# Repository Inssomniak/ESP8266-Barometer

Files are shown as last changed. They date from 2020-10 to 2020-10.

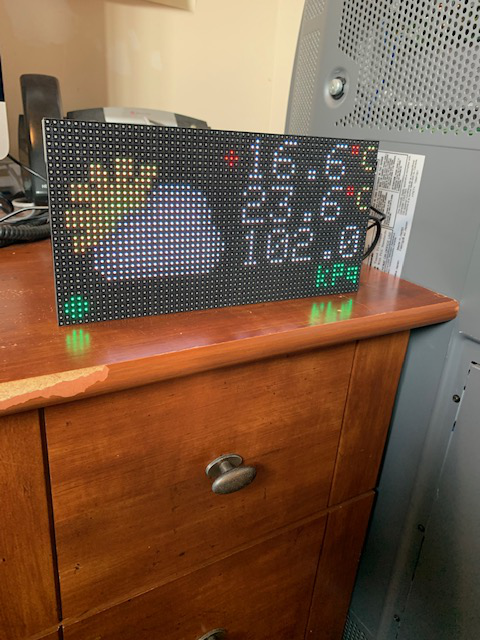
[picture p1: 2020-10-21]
images/image-4.jpg

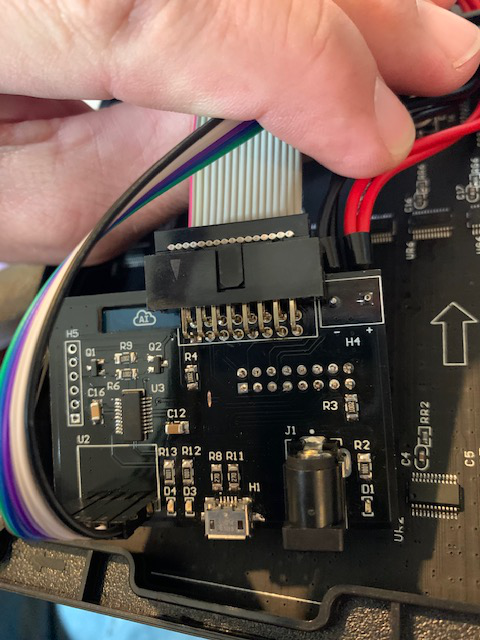
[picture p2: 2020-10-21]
images/IMG_0619.jpg

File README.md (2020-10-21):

# ESP8266-Barometer
ESP8266 Based Barometer on HUB75 LED Matrix with external sensor.  See https://github.com/2dom/PxMatrix for wiring, and information on the Library.
Arduino IDE

LED Matrix barometer on an AliExpress P5 Led Matrix 1/16 scan. Uses pxMatrix library.  BMP280 Pressure/temp sensor.
PCB Designed and made by me with onboard nodemcu style TTL serial converter, ESP-07 type module, 3v3 voltage, support for all scan types.
PCB Gerber is missing a pulldown resistor 10k on GPIO15, I soldered it across to ground right on the ESP-07 module
Depending on your LED Matrix, you have to cut a trace for E Scan line or remove the pins from the header before assembly so the flash GPIOs arent accidentally pulled LOW.

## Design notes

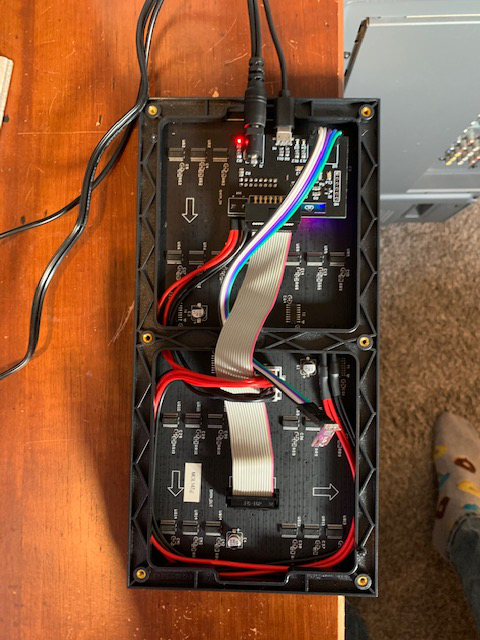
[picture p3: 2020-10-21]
images/image.jpg

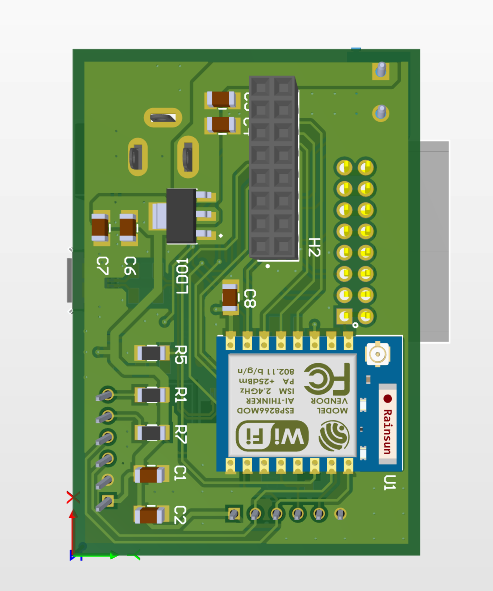
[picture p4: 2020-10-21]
Barometer Gerbers/3D/Screenshot_6.png

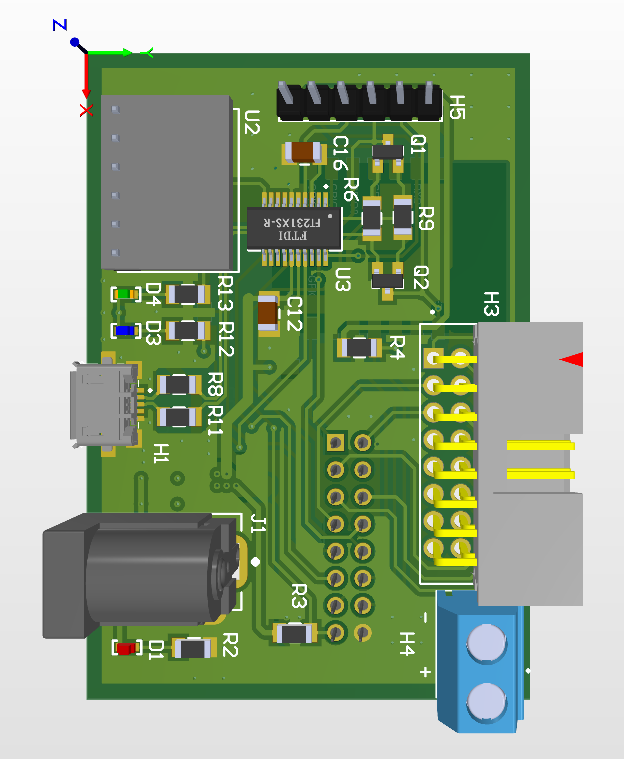
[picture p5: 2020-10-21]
Barometer Gerbers/3D/Screenshot_5.png

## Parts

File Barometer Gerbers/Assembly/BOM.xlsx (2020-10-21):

Designator | Comment | Description | Footprint | Manufacturer | Mfr.PN | Quantity
U3 | FT231XS-R | USB Bridge, USB to UART USB 2.0 UART Interface 20-SSOP | FT231XS-R | FTDI | FT231XS-R | 1
U2 | GY_BMP280_MODULE | environmental sensor with temperature, barometric pressure | BMP280_MODULE | KOOBOOK | KB039 | 1
U1 | ESP8266-07 | self-contained Wi-Fi network solution | ESP8266-07_MODULE | Reland Sung | 722704676397 | 1
R8, R11 | 27R | 27 ±5% 0.25W, 1/4W Chip Resistor 1206 (3216 Metric) Automotive AEC-Q200 Thick Film | R3216 | Stackpole Electronics Inc | RMCF1206JT27R0 | 2
R2, R12, R13 | 1K | 1 ±1% 0.25W, 1/4W Chip Resistor 1206 (3216 Metric) Automotive AEC-Q200 Thick Film | R3216 | Stackpole Electronics Inc | RMCF1206FT1K00 | 3
R1, R3, R4, R5, R6, R7, R9 | 10K | 10 ±1% 0.25W, 1/4W Chip Resistor 1206 (3216 Metric) Automotive AEC-Q200 Thick Film | R3216 | RMCF1206FT10K0 | Stackpole Electronics Inc | 7
Q1, Q2 | MMBT3904 | Bipolar _BJT_ Transistor NPN 40V 200mA 270MHz 350mW Surface Mount SOT-23-3 | MMBT3904 | STMicroelectronics | MMBT3904 | 2
LDO1 | TLV1117LV33DCYR | 1-A, low-dropout voltage regulator 4-SOT-223 -40 to 125 | TLV1117LV33DCYR | Texas Instruments | TLV1117LV33DCYR | 1
J1 | PJ-002A | 2,0 x 6,5 mm, 2,5 A, Yatay, AÃ§Ä±k Delik, Dc GÃ¼Ã§ JakÄ± KonnektÃ¶rÃ¼ | PJ-002A | CUI Devices | PJ-002A | 1
H5 | PH1-06-UA | Connector Header Through Hole 6 position 0.100" (2.54mm) | PH1-06-UA | Adam Tech | PH1-06-UA | 1
H4 | TB002-500-02BE | 2~24 Poles, Screw Type, Horizontal, 5.0 Pitch, 22~12 _AWG_, Terminal Block Connector | TB002-500-02BE | CUI Devices | TB002-500-02BE | 1
H3 | 302-R161 | CONN HEADER R/A 16POS 2.54MM | 302-R161 | On Shore Technology Inc. | 302-R161 | 1
H2 | PPTC082LFBN-RC | 16 Position Header Connector Through Hole | PPTC082LFBN-RC | Sullins Connector Solutions | PPTC082LFBN-RC | 1
H1 | 1981584-1 | Conn Micro USB 2.0 Type AB RCP 5 POS 0.65mm Solder RA SMD 5 Terminal 1 Port T/R | 1981584-1 | TE Connectivity | 1981584-1 | 1
D4 | LED_GREEN | Green 520nm LED Indication - Discrete 3.2V 0603 (1608 Metric) | LED0603-GRENN | Würth Elektronik | 150060GS75000 | 1
D3 | LED_BLUE | Blue 470nm LED Indication - Discrete 3.2V 0603 (1608 Metric) | LED0603-BLUE | Würth Elektronik | 150060BS75000 | 1
D1 | RED_LED | Red 630nm LED Indication - Discrete 1.9V 0603 (1608 Metric) | LED0603-RED | Würth Elektronik | 150060SS75000 | 1
C5, C16 | 0.1uF | ±10% 50V Ceramic Capacitor X7R 1206 (3216 Metric) | C3216 | Samsung Electro-Mechanics | CL31B104KBCNNNC | 2
C4, C6, C7 | 10uF | -20%, +80% 10V Ceramic Capacitor Y5V (F) 1206 (3216 Metric) | C3216 | Samsung Electro-Mechanics | CL31F106ZPHNNNE | 3
C2, C12 | 2.2uF | ±10% 25V Ceramic Capacitor X7R 1206 (3216 Metric) | C3216 | Samsung Electro-Mechanics | CL31B225KAHNNNE | 2
C1, C8 | 220uF | SMD capacitor X6S(EIA) with capacitance 220uF Tol.20%. Rated voltage 4Vdc 105C | C3216 | Murata Electronics | GRM31CC80G227ME11L | 2

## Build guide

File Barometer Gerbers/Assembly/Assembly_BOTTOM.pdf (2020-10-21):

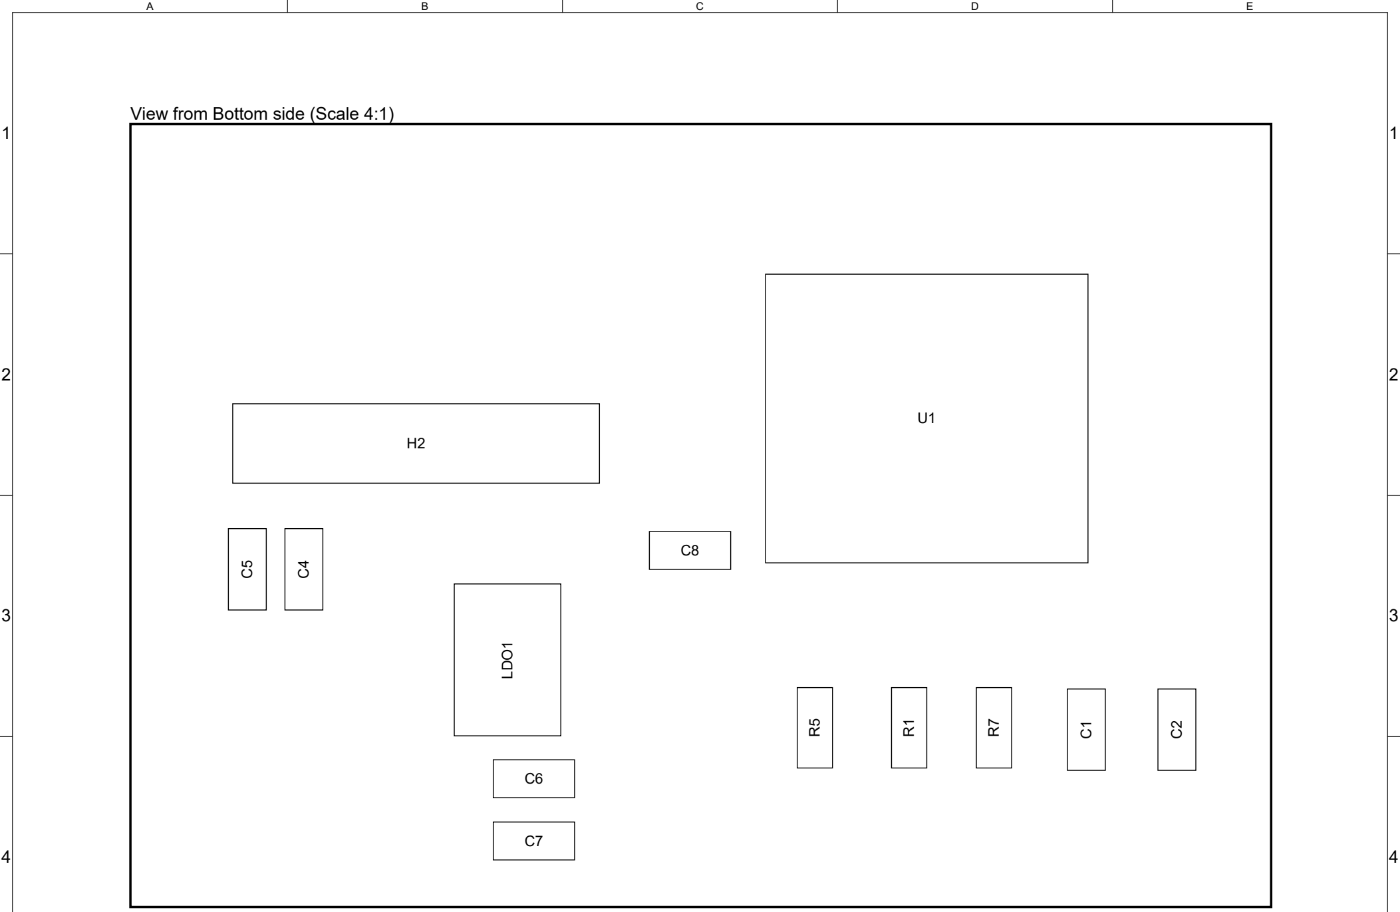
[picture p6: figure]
R⁷ LDO¹; View from Bottom side (Scale 4:1)

A

B

C

D

E

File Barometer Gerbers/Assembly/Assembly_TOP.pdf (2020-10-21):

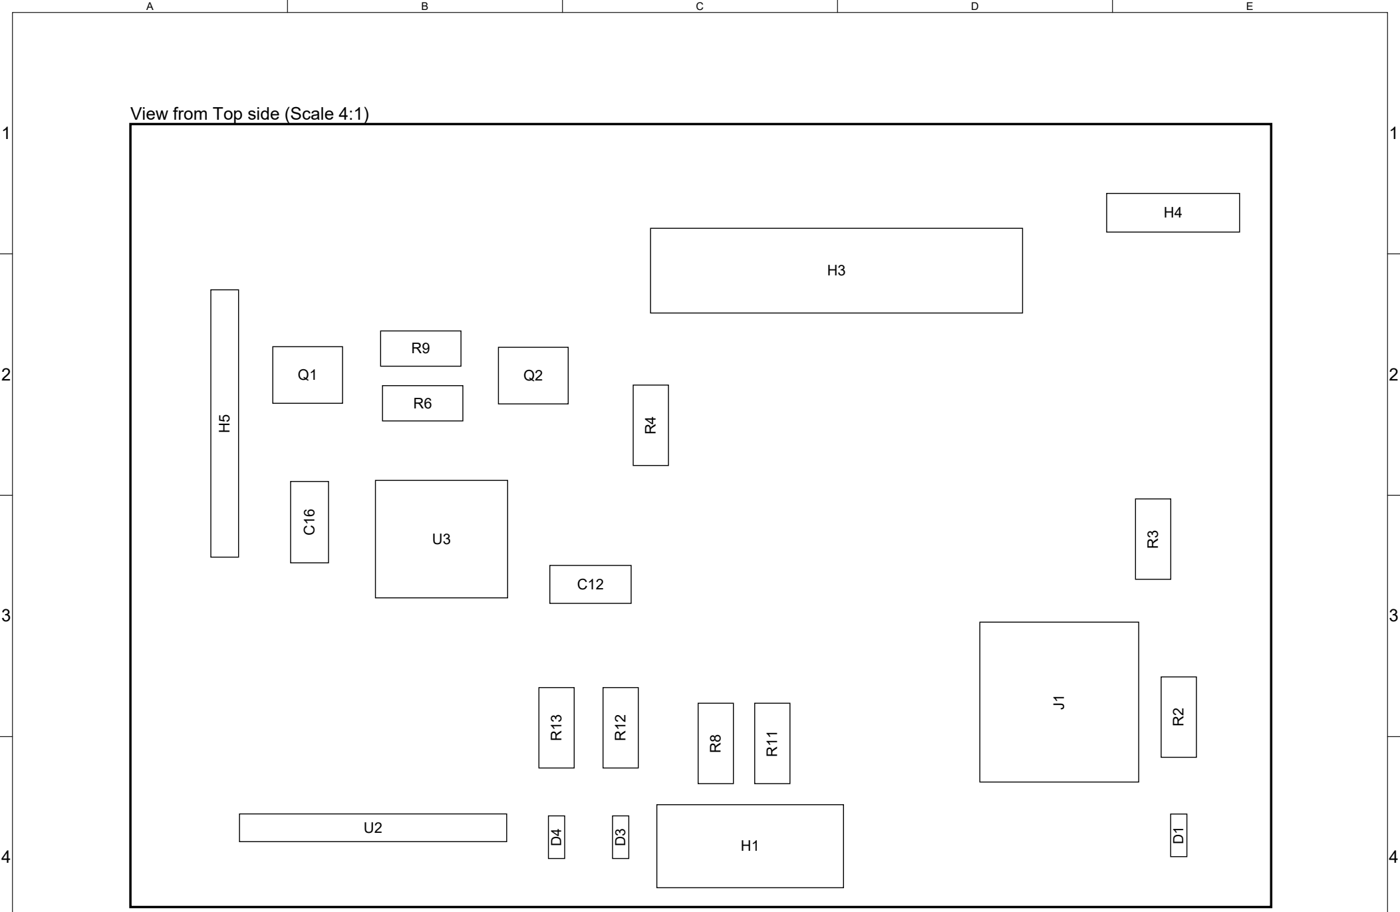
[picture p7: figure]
View from Top side (Scale 4:1)

A

B

C

D

E

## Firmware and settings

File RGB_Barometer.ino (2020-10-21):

// ----------------------------
// Standard Libraries - Already Installed if you have ESP8266 set up
// ----------------------------


#include <Ticker.h>
#include <ESP8266WiFi.h>
#include <ESP8266mDNS.h>
#include <ESP8266HTTPClient.h>
#include <mDNSResolver.h>
#include <Wire.h>
#include <Adafruit_BMP280.h>

// ----------------------------
// Additional Libraries - each one of these will need to be installed.
// ----------------------------


#include <PxMatrix.h>
// The library for controlling the LED Matrix
// Needs to be manually downloaded and installed
// https://github.com/2dom/PxMatrix


Ticker display_ticker;

// Pins for LED MATRIX
#define P_LAT 16
#define P_A 5
#define P_B 4
#define P_C 15
#define P_OE 2
#define P_D 12
#define P_E 0

#define BRIGHTNESS 32                   //  20-255
#define DISPLAY 40                      //  10-50 is OK, too much possible crash or flicker 
#define SENSOR1_NAME "temp1.local"
#define OFFSET 2600                     //  Pressure offset for ~625ft Altitude above sea level.  https://novalynx.com/manuals/bp-elevation-correction-tables.pdf
#define REFRESH 60                      //  Matrix data refresh in seconds

// PxMATRIX display(32,16,P_LAT, P_OE,P_A,P_B,P_C);
PxMATRIX display(64, 32, P_LAT, P_OE, P_A, P_B, P_C, P_D);
//PxMATRIX display(64, 32, P_LAT, P_OE, P_A, P_B, P_C, P_D, P_E);

Adafruit_BMP280 bmp; // use I2C interface

const char* ssid = "OptionsDSL";
const char* password = "9057722572";

IPAddress ServerIP (0, 0, 0, 0);
using namespace mDNSResolver;
WiFiUDP udp;
Resolver resolver(udp);

float newpressure = 96.5;
float curpressure;
float curtemperature;
float sensor1temp = 0;

unsigned long time_now = 0;
int period = 0;


void setup() {
  Serial.begin(115200);

  display.begin(16);
  display.setFastUpdate(true);
  display.clearDisplay();
  Serial.print(F("Pixel draw latency in us: "));
  unsigned long start_timer = micros();
  display.drawPixel(1, 1, 0);
  unsigned long delta_timer = micros() - start_timer;
  Serial.println(delta_timer);

  Serial.print(F("Display update latency in us: "));
  start_timer = micros();
  display.display(0);
  delta_timer = micros() - start_timer;
  Serial.println(delta_timer);

  display_ticker.attach(0.002, display_updater);
  display.clearDisplay();
  display.setBrightness(BRIGHTNESS);

  WiFi.mode(WIFI_STA);
  WiFi.begin(ssid, password);
  display.setCursor(0, 0);
  display.println(F("Connect.."));
  while (WiFi.status() != WL_CONNECTED) {
    delay(1000);
  }
  display.println(F("Success!"));
  display.print(F("Sensor1:"));
  resolve_dns();
  if (ServerIP == INADDR_NONE) {
    display.println(F("No"));
  }
  else {
    display.println(F("OK"));
  }
  Serial.println("Disabling Serial Port");
  Serial.flush();
  Serial.end();
  // Disable serial port.
  pinMode(1, FUNCTION_3);    //GPIO 1 (TX) swap the pin to a GPIO.
  pinMode(3, FUNCTION_3);    //GPIO 3 (RX) swap the pin to a GPIO.
  Wire.begin(1, 3);
  delay(500);

  // Setting up BMP280 Sensor
  bmp.begin();
  bmp.setSampling(Adafruit_BMP280::MODE_NORMAL,     /* Operating Mode. */
                  Adafruit_BMP280::SAMPLING_X2,     /* Temp. oversampling */
                  Adafruit_BMP280::SAMPLING_X16,    /* Pressure oversampling */
                  Adafruit_BMP280::FILTER_X16,      /* Filtering. */
                  Adafruit_BMP280::STANDBY_MS_500); /* Standby time. */

  delay(2500);
  display.clearDisplay();
  display.setCursor(0, 0);
  display.println(bmp.readTemperature(), 3);
  display.println(bmp.readPressure(), 3);
  delay(3000);
  display.clearDisplay();

  resolver.setLocalIP(WiFi.localIP());


}  // End of Setup

// ISR for display refresh
void display_updater()
{
  display.display(DISPLAY);
}



// Converted using the following site: http://www.rinkydinkelectronics.com/t_imageconverter565.php

uint16_t static stormy[] = {

  0x0000, 0x0000, 0x0000, 0x0000, 0x0000, 0x0000, 0x0000, 0x0000, 0x0000, 0x0000, 0x0000, 0x0000, 0x0000, 0x0000, 0x0000, 0x0000, 0x0000, 0x0000, 0x0000, 0x0000, 0x0000, 0x0000, 0x0000, 0x0000, 0x0000, 0x0000, 0x0000, 0x0000, 0x0000, 0x0000, 0x0000, 0x0000,
  0x0000, 0x0000, 0x0000, 0x0000, 0x0000, 0x0000, 0x0000, 0x0000, 0x0000, 0x0000, 0x0000, 0x0000, 0x0000, 0x0000, 0x0000, 0x0000, 0x0000, 0x0000, 0x0000, 0x0000, 0x0000, 0x0000, 0x0000, 0x0000, 0x0000, 0x0000, 0x0000, 0x0000, 0x0000, 0x0000, 0x0000, 0x0000,
  0x0000, 0x0000, 0x0000, 0x0000, 0x0000, 0x0000, 0x0000, 0x0000, 0x0000, 0x0000, 0x0000, 0x0000, 0x0000, 0x0000, 0x0000, 0x0000, 0x0000, 0x0000, 0x0000, 0x0000, 0x0000, 0x0000, 0x0000, 0x0000, 0x0000, 0x0000, 0x0000, 0x0000, 0x0000, 0x0000, 0x0000, 0x0000,
  0x0000, 0x0000, 0x0000, 0x0000, 0x0000, 0x0000, 0x0000, 0x0000, 0x0000, 0x0000, 0x0000, 0x0000, 0x0000, 0x0000, 0x0000, 0x0000, 0x0000, 0x0000, 0x0000, 0x0000, 0x0000, 0x0000, 0x0000, 0x0000, 0x0000, 0x0000, 0x0000, 0x0000, 0x0000, 0x0000, 0x0000, 0x0000,
  0x0000, 0x0000, 0x0000, 0x0000, 0x0000, 0x0000, 0x0000, 0x0000, 0x0000, 0x0000, 0x0000, 0x0000, 0x0000, 0x0000, 0x0000, 0x0000, 0x0000, 0x0000, 0x0000, 0x0000, 0x0000, 0x0000, 0x0000, 0x0000, 0x0000, 0x0000, 0x0000, 0x0000, 0x0000, 0x0000, 0x0000, 0x0000,
  0x0000, 0x0000, 0x0000, 0x0000, 0x0000, 0x0000, 0x0000, 0x0000, 0x0000, 0x0000, 0x0000, 0x0000, 0x0000, 0x0000, 0x0000, 0x0000, 0x0000, 0x0000, 0x0000, 0x0000, 0x0000, 0x0000, 0x0000, 0x0000, 0x0000, 0x0000, 0x0000, 0x0000, 0x0000, 0x0000, 0x0000, 0x0000,
  0x0000, 0x0000, 0x0000, 0x0000, 0x0000, 0x0000, 0x0000, 0x0000, 0x0000, 0x0000, 0x0000, 0x0000, 0x0000, 0x0000, 0x0000, 0x0000, 0x2124, 0x2124, 0x2124, 0x2124, 0x2124, 0x0000, 0x0000, 0x0000, 0x0000, 0x0000, 0x0000, 0x0000, 0x0000, 0x0000, 0x0000, 0x0000,
  0x0000, 0x0000, 0x0000, 0x0000, 0x0000, 0x0000, 0x0000, 0x0000, 0x0000, 0x0000, 0x0000, 0x0000, 0x0000, 0x0000, 0x2124, 0x2124, 0x2124, 0x2945, 0x2965, 0x2945, 0x2124, 0x2124, 0x2965, 0x0000, 0x0000, 0x0000, 0x0000, 0x0000, 0x0000, 0x0000, 0x0000, 0x0000,
  0x0000, 0x0000, 0x0000, 0x0000, 0x0000, 0x0000, 0x0000, 0x0000, 0x0000, 0x0000, 0x0000, 0x0000, 0x0000, 0x2124, 0x2124, 0x31A6, 0x52AA, 0x632D, 0x634D, 0x630C, 0x4229, 0x2945, 0x2124, 0x2965, 0x0000, 0x0000, 0x0000, 0x0000, 0x0000, 0x0000, 0x0000, 0x0000,
  0x0000, 0x0000, 0x0000, 0x0000, 0x0000, 0x0000, 0x0000, 0x0000, 0x0000, 0x0000, 0x0000, 0x0000, 0x2124, 0x2124, 0x39C7, 0x6B4D, 0x738E, 0x6B8E, 0x6B8E, 0x6B8E, 0x738E, 0x52AB, 0x2945, 0x2124, 0x0000, 0x0000, 0x0000, 0x0000, 0x0000, 0x0000, 0x0000, 0x0000,
  0x0000, 0x0000, 0x0000, 0x0000, 0x0000, 0x0000, 0x0000, 0x0000, 0x0000, 0x2104, 0x2124, 0x2124, 0x2104, 0x2945, 0x632C, 0x6B8E, 0x6B6E, 0x6B6E, 0x6B6E, 0x6B6E, 0x6B6E, 0x738E, 0x4249, 0x2104, 0x2104, 0x0000, 0x0000, 0x0000, 0x0000, 0x0000, 0x0000, 0x0000,
  0x0000, 0x0000, 0x0000, 0x0000, 0x0000, 0x0000, 0x0000, 0x0000, 0x2124, 0x2124, 0x2945, 0x39C7, 0x39E8, 0x4249, 0x6B8E, 0x6B6E, 0x6B6E, 0x6B6E, 0x6B6E, 0x6B6E, 0x6B6E, 0x6B8E, 0x630C, 0x2945, 0x2104, 0x0000, 0x0000, 0x0000, 0x0000, 0x0000, 0x0000, 0x0000,
  0x0000, 0x0000, 0x0000, 0x0000, 0x0000, 0x0000, 0x0000, 0x2945, 0x2124, 0x3186, 0x5AEC, 0x6B8E, 0x6B8E, 0x6B8E, 0x6B6E, 0x6B6E, 0x6B6E, 0x6B6E, 0x6B6E, 0x6B6E, 0x6B6E, 0x6B8E, 0x6B4D, 0x2965, 0x2124, 0x0000, 0x0000, 0x0000, 0x0000, 0x0000, 0x0000, 0x0000,
  0x0000, 0x0000, 0x0000, 0x0000, 0x0000, 0x0000, 0x0000, 0x2124, 0x2945, 0x5AEB, 0x738E, 0x6B6E, 0x6B6E, 0x6B6E, 0x6B6E, 0x6B6E, 0x6B6E, 0x6B6E, 0x6B6E, 0x6B6E, 0x6B6E, 0x6B8E, 0x634D, 0x2986, 0x2124, 0x2124, 0x0000, 0x0000, 0x0000, 0x0000, 0x0000, 0x0000,
  0x0000, 0x0000, 0x0000, 0x0000, 0x0000, 0x0000, 0x2124, 0x2104, 0x3186, 0x6B6E, 0x6B6E, 0x6B6E, 0x6B6E, 0x6B6E, 0x6B6E, 0x6B6E, 0x6B6E, 0x6B6E, 0x6B6E, 0x6B6E, 0x6B6E, 0x6B6E, 0x6B6E, 0x632D, 0x4208, 0x2124, 0x2124, 0x0000, 0x0000, 0x0000, 0x0000, 0x0000,
  0x0000, 0x0000, 0x0000, 0x0000, 0x0000, 0x2945, 0x2124, 0x39E7, 0x5AEC, 0x6B8E, 0x6B6E, 0x6B6E, 0x6B6E, 0x6B6E, 0x6B6E, 0x6B6E, 0x6B6E, 0x6B6E, 0x6B6E, 0x6B6E, 0x6B6E, 0x6B6E, 0x6B6E, 0x6B8E, 0x6B6E, 0x39C7, 0x2124, 0x0000, 0x0000, 0x0000, 0x0000, 0x0000,
  0x0000, 0x0000, 0x0000, 0x0000, 0x0000, 0x2104, 0x39C7, 0x6B6E, 0x6B8E, 0x6B6E, 0x6B6E, 0x6B6E, 0x6B6E, 0x6B6E, 0x6B6E, 0x6B6E, 0x738D, 0x83CB, 0x738D, 0x6B6E, 0x6B6E, 0x6B6E, 0x6B6E, 0x6B6E, 0x738E, 0x4A69, 0x2104, 0x3186, 0x0000, 0x0000, 0x0000, 0x0000,
  0x0000, 0x0000, 0x0000, 0x0000, 0x2124, 0x2104, 0x4A69, 0x738E, 0x6B6E, 0x6B6E, 0x6B6E, 0x6B6E, 0x6B6E, 0x6B6E, 0x6B6E, 0x636E, 0xBC47, 0xECE2, 0x738D, 0x6B6E, 0x6B6E, 0x6B6E, 0x6B6E, 0x6B6E, 0x738E, 0x4A49, 0x2104, 0x2124, 0x0000, 0x0000, 0x0000, 0x0000,
  0x0000, 0x0000, 0x0000, 0x0000, 0x3186, 0x2104, 0x39E7, 0x6B8E, 0x6B8E, 0x6B8E, 0x6B8E, 0x6B8E, 0x6B8E, 0x6B8E, 0x6B8E, 0x7BAC, 0xF501, 0xAC28, 0x6B6F, 0x6B8E, 0x6B8E, 0x6B8E, 0x6B8E, 0x738E, 0x634D, 0x3186, 0x2124, 0x0000, 0x0000, 0x0000, 0x0000, 0x0000,
  0x0000, 0x0000, 0x0000, 0x0000, 0x0000, 0x2124, 0x2124, 0x4228, 0x5B0C, 0x630C, 0x630C, 0x630C, 0x630C, 0x630C, 0x5AEC, 0xB426, 0xF501, 0x93CA, 0x632C, 0x5B0C, 0x630C, 0x630C, 0x630C, 0x52CB, 0x31A6, 0x2124, 0x2124, 0x0000, 0x0000, 0x0000, 0x0000, 0x0000,
  0x0000, 0x0000, 0x0000, 0x0000, 0x0000, 0x0000, 0x2124, 0x2124, 0x2124, 0x2124, 0x2124, 0x2124, 0x2124, 0x2125, 0x41A4, 0xECC1, 0xFD21, 0xD462, 0x3164, 0x2124, 0x2124, 0x2124, 0x2124, 0x2124, 0x2124, 0x2124, 0x0000, 0x0000, 0x0000, 0x0000, 0x0000, 0x0000,
  0x0000, 0x0000, 0x0000, 0x0000, 0x0000, 0x0000, 0x0000, 0x2104, 0x2124, 0x2124, 0x2124, 0x2124, 0x2124, 0x1905, 0x6A63, 0xF4E1, 0xFD21, 0xCC22, 0x10E5, 0x2124, 0x2124, 0x2124, 0x2124, 0x2945, 0x2945, 0x0000, 0x0000, 0x0000, 0x0000, 0x0000, 0x0000, 0x0000,
  0x0000, 0x0000, 0x0000, 0x0000, 0x0000, 0x0000, 0x0000, 0x0000, 0x0000, 0x0000, 0x0000, 0x0000, 0x0000, 0x0000, 0x0000, 0xFD01, 0xFD01, 0xFD20, 0xFD40, 0x0000, 0x0000, 0x0000, 0x0000, 0x0000, 0x0000, 0x0000, 0x0000, 0x0000, 0x0000, 0x0000, 0x0000, 0x0000,
  0x0000, 0x0000, 0x0000, 0x0000, 0x0000, 0x0000, 0x0000, 0x0000, 0x0000, 0x0000, 0x0000, 0x0000, 0x0000, 0x0000, 0xFD01, 0xFD01, 0xFD21, 0xFD01, 0xFD40, 0x0000, 0x0000, 0x0000, 0x0000, 0x0000, 0x0000, 0x0000, 0x0000, 0x0000, 0x0000, 0x0000, 0x0000, 0x0000,
  0x0000, 0x0000, 0x0000, 0x0000, 0x0000, 0x0000, 0x0000, 0x0000, 0x0000, 0x0000, 0x0000, 0x0000, 0x0000, 0x0000, 0xFD21, 0xFD21, 0xFD21, 0xFD01, 0x0000, 0x0000, 0x0000, 0x0000, 0x0000, 0x0000, 0x0000, 0x0000, 0x0000, 0x0000, 0x0000, 0x0000, 0x0000, 0x0000,
  0x0000, 0x0000, 0x0000, 0x0000, 0x0000, 0x0000, 0x0000, 0x0000, 0x0000, 0x0000, 0x0000, 0x0000, 0x0000, 0x0000, 0x0000, 0xFD01, 0xFD01, 0xFD40, 0x0000, 0x0000, 0x0000, 0x0000, 0x0000, 0x0000, 0x0000, 0x0000, 0x0000, 0x0000, 0x0000, 0x0000, 0x0000, 0x0000,
  0x0000, 0x0000, 0x0000, 0x0000, 0x0000, 0x0000, 0x0000, 0x0000, 0x0000, 0x0000, 0x0000, 0x0000, 0x0000, 0x0000, 0xFD21, 0xFD21, 0xFD21, 0x0000, 0x0000, 0x0000, 0x0000, 0x0000, 0x0000, 0x0000, 0x0000, 0x0000, 0x0000, 0x0000, 0x0000, 0x0000, 0x0000, 0x0000,
  0x0000, 0x0000, 0x0000, 0x0000, 0x0000, 0x0000, 0x0000, 0x0000, 0x0000, 0x0000, 0x0000, 0x0000, 0x0000, 0x0000, 0xFCC1, 0xFD21, 0xCCC0, 0x0000, 0x0000, 0x0000, 0x0000, 0x0000, 0x0000, 0x0000, 0x0000, 0x0000, 0x0000, 0x0000, 0x0000, 0x0000, 0x0000, 0x0000,
  0x0000, 0x0000, 0x0000, 0x0000, 0x0000, 0x0000, 0x0000, 0x0000, 0x0000, 0x0000, 0x0000, 0x0000, 0x0000, 0x0000, 0x0000, 0x0000, 0x0000, 0x0000, 0x0000, 0x0000, 0x0000, 0x0000, 0x0000, 0x0000, 0x0000, 0x0000, 0x0000, 0x0000, 0x0000, 0x0000, 0x0000, 0x0000,
  0x0000, 0x0000, 0x0000, 0x0000, 0x0000, 0x0000, 0x0000, 0x0000, 0x0000, 0x0000, 0x0000, 0x0000, 0x0000, 0x0000, 0x0000, 0x0000, 0x0000, 0x0000, 0x0000, 0x0000, 0x0000, 0x0000, 0x0000, 0x0000, 0x0000, 0x0000, 0x0000, 0x0000, 0x0000, 0x0000, 0x0000, 0x0000,
  0x0000, 0x0000, 0x0000, 0x0000, 0x0000, 0x0000, 0x0000, 0x0000, 0x0000, 0x0000, 0x0000, 0x0000, 0x0000, 0x0000, 0x0000, 0x0000, 0x0000, 0x0000, 0x0000, 0x0000, 0x0000, 0x0000, 0x0000, 0x0000, 0x0000, 0x0000, 0x0000, 0x0000, 0x0000, 0x0000, 0x0000, 0x0000,
  0x0000, 0x0000, 0x0000, 0x0000, 0x0000, 0x0000, 0x0000, 0x0000, 0x0000, 0x0000, 0x0000, 0x0000, 0x0000, 0x0000, 0x0000, 0x0000, 0x0000, 0x0000, 0x0000, 0x0000, 0x0000, 0x0000, 0x0000, 0x0000, 0x0000, 0x0000, 0x0000, 0x0000, 0x0000, 0x0000, 0x0000, 0x0000,
};
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
void loop() {

  resolver.loop();

  if (millis() >= time_now + period) { // Only check pressure/temp every 'period' to prevent rapid matrix updates.
    if (period == 0) {
      period = REFRESH * 1000;
    }
    time_now += period;
    newpressure = round(((bmp.readPressure() + OFFSET) / 1000) * 10) / 10;  // Read pressure accurate to 1 decimal.

    if (curpressure  != newpressure) {    // Only update icon if pressure is different.
      drawIcon(0, 0, newpressure);        // Run to draw Icons (x, y, pressure)
    }
    if (curpressure > newpressure) {
      trend_red(1, 27);       // Draw trending red dot after icon, as to not have it overwritten with icon.
    }
    if (curpressure < newpressure) {
      trend_green(1, 27);     // Draw trending green dot after icon, as to not have it overwritten with icon.
    }

    curpressure = newpressure;

    // ----  Remote Sensor Read Code

    if (WiFi.status() == WL_CONNECTED) { //Check WiFi connection status

      WiFiClient httpClient;
      HTTPClient http;  //Declare an object of class HTTPClient
      if (ServerIP == INADDR_NONE) {
        resolve_dns();
      }
      String ipStr = String(ServerIP[0]) + '.' + String(ServerIP[1]) + '.' + String(ServerIP[2]) + '.' + String(ServerIP[3]);
      String StringIP;
      StringIP += "http://";
      StringIP += ipStr;
      StringIP += "/temperaturec";

      http.begin(httpClient, StringIP);         //Specify request destination

      int httpCode = http.GET();                //Send the request

      if (httpCode > 0) {                       //Check the returning code
        String payload = http.getString();      //Get the request response payload
        sensor1temp = payload.toFloat();
        //Serial.println(sensor1temp);          //Print the response payload
      }
      if (http.connected()) http.end();

    }

    // -----

    drawTemperatures(sensor1temp, bmp.readTemperature());
    drawPressure(curpressure);

  }


}

// -------------------------------------------------------------



void drawIcon(int x, int y, float pressure)
{
  int imageHeight = 32;
  int imageWidth = 32;
  int counter = 0;

  if (pressure > 95 && pressure <= 97) {
    for (int yy = 0; yy < imageHeight; yy++) {
      for (int xx = 0; xx < imageWidth; xx++) {
        display.drawPixel(xx + x , yy + y, stormy[counter]);
        counter++;
      }
    }
  }

  if (pressure > 97 && pressure <= 99) {
    for (int yy = 0; yy < imageHeight; yy++) {
      for (int xx = 0; xx < imageWidth; xx++) {
        display.drawPixel(xx + x , yy + y, rain[counter]);
        counter++;
      }
    }
  }

  if (pressure > 99 && pressure <= 101) {
    for (int yy = 0; yy < imageHeight; yy++) {
      for (int xx = 0; xx < imageWidth; xx++) {
        display.drawPixel(xx + x , yy + y, change[counter]);
        counter++;
      }
    }
  }

  if (pressure > 101 && pressure <= 102.1) {
    for (int yy = 0; yy < imageHeight; yy++) {
      for (int xx = 0; xx < imageWidth; xx++) {
        display.drawPixel(xx + x , yy + y, fair[counter]);
        counter++;
      }
    }
  }

  if (pressure > 102.1 && pressure <= 105) {
    for (int yy = 0; yy < imageHeight; yy++) {
      for (int xx = 0; xx < imageWidth; xx++) {
        display.drawPixel(xx + x , yy + y, very_dry[counter]);
        counter++;
      }
    }
  }

}

// ------------------------------------------------------------

void drawTemperatures(float outsidetemp, float insidetemp) {     // Draw Temperatures to matrix.

  display.fillRect(29, 1, 63, 7, 0x0000);     // Erase existing Temperature from matrix.
  display.fillRect(33, 9, 63, 15, 0x0000);    // Erase existing Temperature from matrix.

  if (outsidetemp < 0) {   // Negative Temp
    display.drawLine(29, 4, 31, 4, 0x00DF);
    display.setCursor(33, 1);
    display.print(-outsidetemp, 1);
    if (outsidetemp < 10) {
      icon_degree_c(51, 1);
    } else {
      icon_degree_c(57, 1);
    }

  }
  else {      // Postive Temp
    display.drawLine(29, 4, 31, 4, 0xF800);
    display.drawLine(30, 3, 30, 5, 0xF800);
    display.setCursor(33, 1);
    display.print(outsidetemp, 1);
    if (outsidetemp < 10) {
      icon_degree_c(51, 1);
    } else {
      icon_degree_c(57, 1);
    }
  }

  display.setCursor(33, 9);
  display.print(insidetemp, 1);
  if (insidetemp < 10) {
    icon_degree_c(51, 9);
  } else {
    icon_degree_c(57, 9);
  }

}

// ---------------------------------------------------------


void drawPressure(float pressure) {
  display.fillRect(33, 17, 62, 23, 0x0000);
  display.setCursor(33, 17);
  display.print(pressure, 1);
  icon_kPa(52, 25);
}


void resolve_dns() {

  ServerIP = resolver.search(SENSOR1_NAME);
  if (ServerIP != INADDR_NONE) {
    Serial.print("Resolved: ");
    Serial.println(ServerIP);
  }
  else {
    Serial.println("Not resolved");
  }


}


void trend_red(int x, int y) {
  // 4x4 Red Dot
  uint16_t static red_dot[] = {
    0x0000, 0xF800, 0xF800, 0x0000,   // 0x0020 (4) pixels
    0xF800, 0xF800, 0xF800, 0xF800,   // 0x0020 (8) pixels
    0xF800, 0xF800, 0xF800, 0xF800,   // 0x0020 (12) pixels
    0x0000, 0xF800, 0xF800, 0x0000,   // 0x0020 (16) pixels
  };


  int imageHeight = 4;
  int imageWidth = 4;
  int counter = 0;
  for (int yy = 0; yy < imageHeight; yy++) {
    for (int xx = 0; xx < imageWidth; xx++) {
      display.drawPixel(xx + x , yy + y, red_dot[counter]);
      counter++;
    }
  }
}

void trend_green(int x, int y) {
  // 4x4 Green Dot
  uint16_t static green_dot[] = {
    0x0000, 0x0760, 0x0760, 0x0000,   // 0x0020 (4) pixels
    0x0760, 0x0760, 0x0760, 0x0760,   // 0x0020 (8) pixels
    0x0760, 0x0760, 0x0760, 0x0760,   // 0x0020 (12) pixels
    0x0000, 0x0760, 0x0760, 0x0000,   // 0x0020 (16) pixels
  };

  int imageHeight = 4;
  int imageWidth = 4;
  int counter = 0;
  for (int yy = 0; yy < imageHeight; yy++) {
    for (int xx = 0; xx < imageWidth; xx++) {
      display.drawPixel(xx + x , yy + y, green_dot[counter]);
      counter++;
    }
  }
}


void icon_degree_c(int x, int y) {
  // DegreeC
  uint16_t static degreeC[] = {
    0xF800, 0xF800, 0x0000, 0x0000, 0xFD20, 0xFD20, // t(6) pixels
    0xF800, 0xF800, 0x0000, 0xFD20, 0x0000, 0x0000, // (12) pixels
    0x0000, 0x0000, 0x0000, 0xFD20, 0x0000, 0x0000, // (18) pixels
    0x0000, 0x0000, 0x0000, 0xFD20, 0x0000, 0x0000, // (24) pixels
    0x0000, 0x0000, 0x0000, 0x0000, 0xFD20, 0xFD20, // (30) pixels
  };

  int imageHeight = 5;
  int imageWidth = 6;
  int counter = 0;
  for (int yy = 0; yy < imageHeight; yy++) {
    for (int xx = 0; xx < imageWidth; xx++) {
      display.drawPixel(xx + x , yy + y, degreeC[counter]);
      counter++;
    }
  }
}

void icon_kPa(int x, int y) {
  uint16_t static kPa[] = {
    0x07C0, 0x0000, 0x0000, 0x0000, 0x07C0, 0x07C0, 0x07C0, 0x0000, 0x0000, 0x0000, 0x0000, 0x0000, // (12) pixels
    0x07C0, 0x0000, 0x07C0, 0x0000, 0x07C0, 0x0000, 0x07C0, 0x0000, 0x07C0, 0x07C0, 0x07C0, 0x0000, // (24) pixels
    0x07C0, 0x07C0, 0x0000, 0x0000, 0x07C0, 0x07C0, 0x07C0, 0x0000, 0x07C0, 0x0000, 0x07C0, 0x0000, // (36) pixels
    0x07C0, 0x07C0, 0x0000, 0x0000, 0x07C0, 0x0000, 0x0000, 0x0000, 0x07C0, 0x07C0, 0x07C0, 0x0000, // (48) pixels
    0x07C0, 0x0000, 0x07C0, 0x0000, 0x07C0, 0x0000, 0x0000, 0x0000, 0x0000, 0x0000, 0x07C0, 0x0000, // (60) pixels
  };

  int imageHeight = 5;
  int imageWidth = 12;
  int counter = 0;
  for (int yy = 0; yy < imageHeight; yy++) {
    for (int xx = 0; xx < imageWidth; xx++) {
      display.drawPixel(xx + x , yy + y, kPa[counter]);
      counter++;
    }
  }
}
